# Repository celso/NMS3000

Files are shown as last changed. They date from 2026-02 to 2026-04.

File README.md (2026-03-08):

# Philips Telematico NMS3000 Schematics

This repo containers the KiCad schematics of the Philips Telematico NMS3000 Videotex terminal and small Videotex server implementation.

## Specs

With links to datasheets.

- [Z80 CPU](./datasheets/Z80-CPU.pdf) running at 3MHz
- 27C256 32K (EP)ROM
- 4K RAM (2x [HM3-6527N-5](./datasheets/HM3-6116-9-SRAM.pdf) 2K for CPU, 2K for Video)
- [MR9735](./datasheets/MR9735-video.pdf) Videotex Video Generator
- [EF7910](./datasheets/EF7910PL-modem.pdf) FSK Modem
- [UPD8255A](./datasheets/UPD8255A-IO.pdf) I/O chip
- [PCD8582](./datasheets/PCX8582X-2-EEPROM.pdf) 1K I2C EEPROM for the configuration
- Multiple gate chips, flip-flops, decoders, transceivers and multiplexers: 74HC138, 74HC245, 74HC32, 74HC74, 74HC14, 74155, 4N32, TL072, 74157.

## Schematics

The KiCad files can be found in the [KiCad project directory](./schematics). A PDF rendering version can be found [here](./schematics/NMS3000.pdf).

I reverse engineered the PCB by tracing all the wires and components, measuring signals with the scope and looking at datasheets. The KiCad Electrical Rules Checker shows no errors and I'm fairly confident that the schematics are correct but if you find any errors or have any suggestions, please let me know or PR this repo.

## ROM

The ROM was dumped using a [Retro Chip Tester Pro](https://celso.io/posts/2025/07/19/retro-chip-tester/) and the image can be found [here](./roms).

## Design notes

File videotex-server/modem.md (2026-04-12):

modem.ts is a nodejs cli command that uses the '#!/usr/bin/env NODE_NO_WARNINGS=1 npx tsx' shebang.

the command acts as a proxy between a local USB modem (that connects to an old Teletext terminal) and a WebSocket server and takes two arguments:

--ws WebSocket server endpoint (example: wss://example.com/ws or ws://localhost/ws)
--serial Serial device (example: /dev/cu.usbmodem246802461)

To connect with the local modem we are going to use the npm serialport package.

Note: Teletext uses 7E1 but our serial driver only supports 8N1. We are going to have to convert 8N1 to 7E1 and calculate the parity bit in userland before we send any data to the modem. Similarly when we receive data from the modem, assume it's going to be 7E1, so just remove the parity bit.

Here's how to script goes:

First we connect to the WebSocket server.

We are going to need primitives to send and receive data.

Then the script connects to the serial port at 9600 bauds, 8n1, and sends the modem the following commands:

ATZ
AT+ES=0,0,1
AT+MS=V23C,0
AT+ES=0
AT&K0
AT+IFC=0,0
ATB0
ATE1
ATS2=255

For each command we wait for OK. Echo both the commands and the modem responses in the terminal.

Now we tell the modem to connect to the remote host by sending the ATA command and wait for the CONNECT* string.

Now we send to the WebSocket server the following JSON packet:

{ type: "viewdata_init" }

And wait.

Each time the WS server respond with the following JSON packet:

{ type: "frame", data: base64string }

We decode the data and send it as is to to modem connection.

If we receive bytes from modem when it's connected forward each byte to the websocket server as "key" events:

{ type: "key", key: byte }

If either the modem or the WebSocket disconnect after the conection has been estabilished then error out and exit the script cleanly.

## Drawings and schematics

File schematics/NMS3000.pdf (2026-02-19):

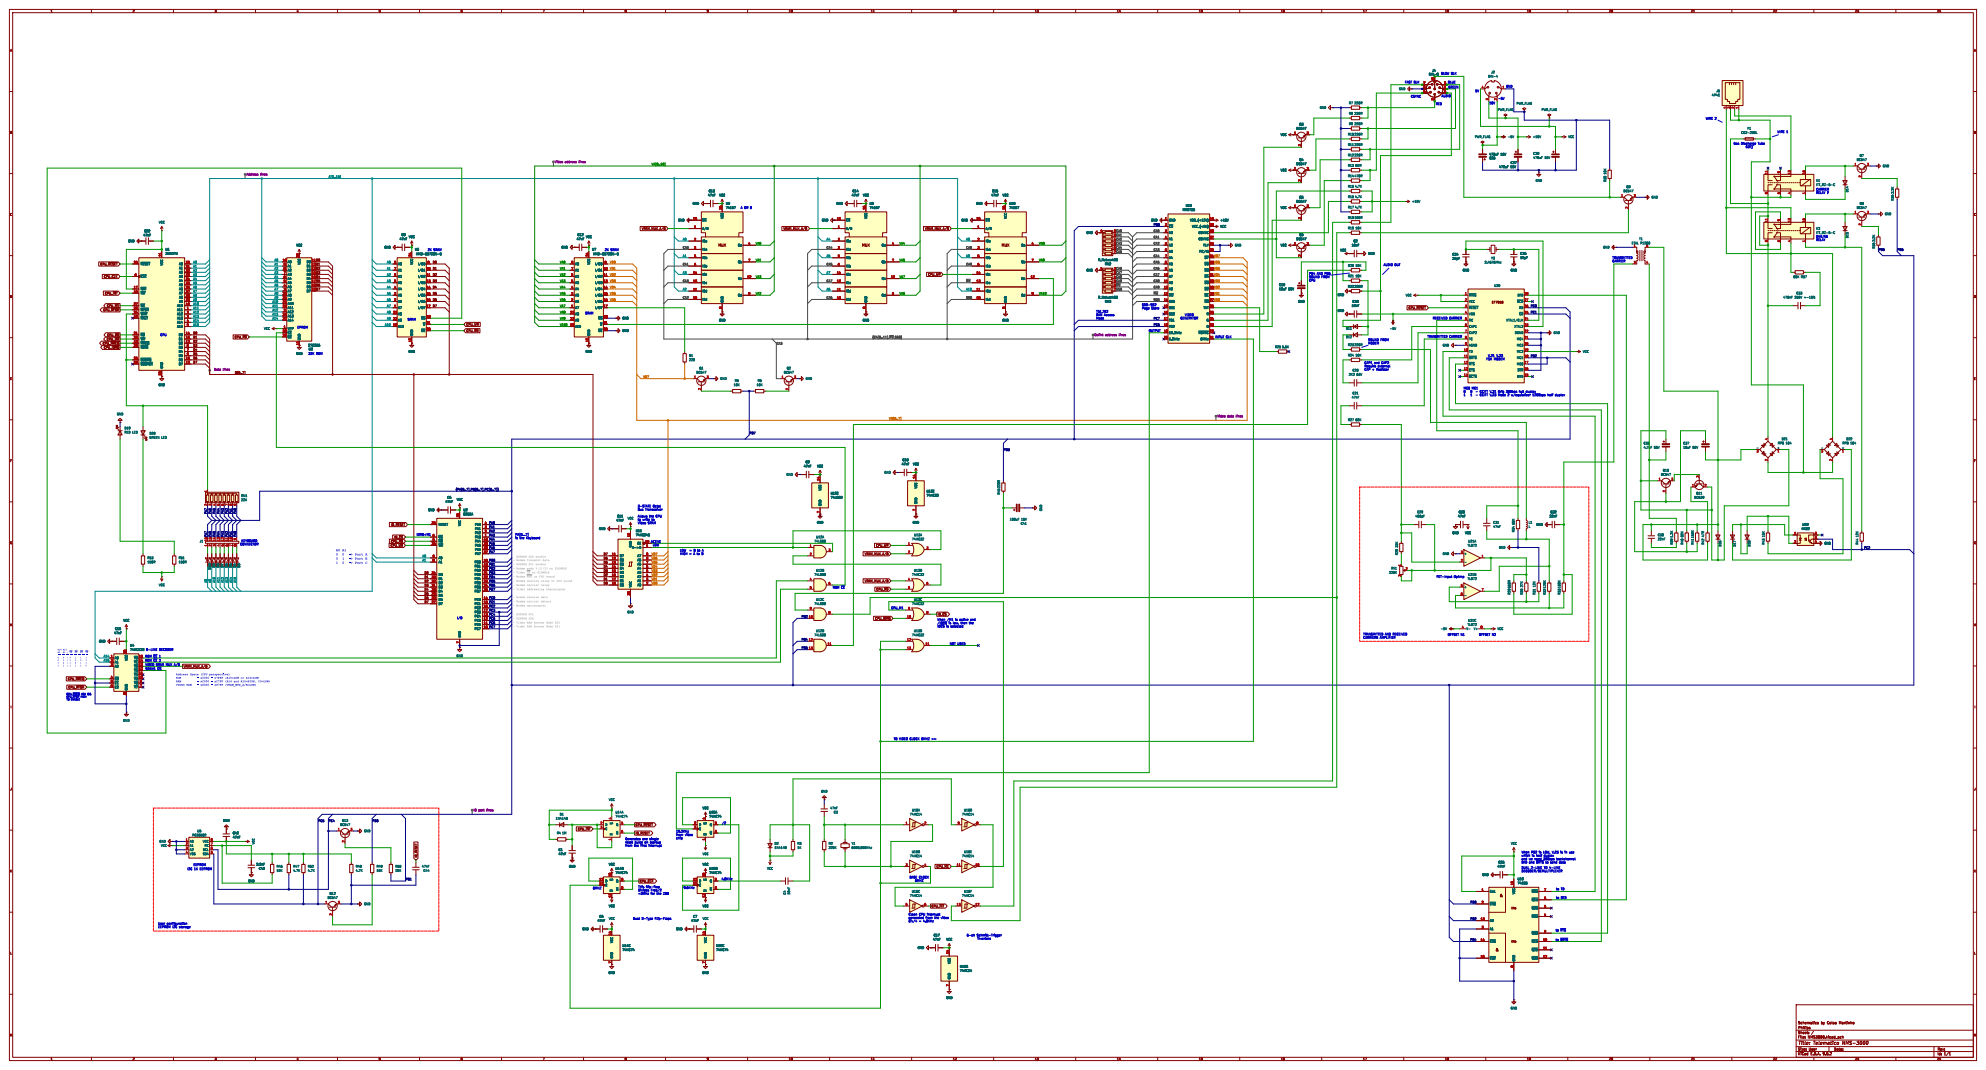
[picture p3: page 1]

SS0-SS2 Page Store TS1,TS2 RAM Access Mode

CAP1 and CAP2 Require external CAP + Resistor

ROM ~{CE} 3-STATE Octal Bus Transceiver Allows the CPU

74HC32 VCC
to write to Video SRAM

LOW = B to A HIGH = A to B

IO~{CS}is selected EEPROMSDA enable
- EEPROMSCL enable
- Modem mode V.21/23 or SLOWBLK
- Video ~{CS} or SLOWBLK
- Modem ~{RTS} or CPU sound

- EEPROMSCL
- EEPROMSDA
- Video RAM Access Mode TS2
- Video RAM Access Mode TS1

When /M1 is active and
/IORQ is low, then the

ROM ~{CE}1 VIDEO SRAM MUX A/B

TO VIDEO CLOCK 6MHZ >> This flip-flop Divides Freq/2 =3MHz for the Z80 Dual D-Type Flip-Flops

Generates one single
reset pulse on startup
from the first interrupt

User configuration EEPROM I2C storage

Id: 1/1 Title: Telematico NMS-3000
